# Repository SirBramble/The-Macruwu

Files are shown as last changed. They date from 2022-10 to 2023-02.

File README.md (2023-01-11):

# The Macruwu
The macro pad for all! (well, at least, if you can understand the Clusterfuck posted here)
The Firmware is based on the Arduino Pico Core by earlephilhower https://github.com/earlephilhower/arduino-pico. 

**This is only a brief overview** The full documentation and instructions can be found in the "Documentation"-folder.

## Components used

I went with the RP2040 based board from seeed studio. It has a fast chip, offers integrated USB support and is only about 6€. However, it has limited GPIO pins. So if you want to build your own, I would recommend using I/O Expanders or something similar. Another option would be to use a raspberry Pi with a RP2040. This Board beaks out most of the RP2040 Pins and has Options for Wi-Fi.

In order to try out different Key switches and keep the Macruwu modular, I decided to use hot swap sockets. They aren’t to expensive, if you order them for AliExpress (about 1\$/10psc). But beware, when soldering. If your board manufacturer decides to give you the shit coating on your Pads, prepare for heavy flux use.

For the I/O Expanders I used the PCA9555 from NXP. They conveniently don’t need a lot of setup and are automatically set to INPUT_PULLUP. The detailed Addressing scheme and co can be found in the Datasheet. But, as per usual nowadays, the I/O expanders are sold out. So, you might want to look for them somewhere else, or find a suitable replacement. But if you can find them, I can recommend the NXP Expanders. They need minimal to no Software Setup and I haven't had a dead one so far.

The level shifter (TXU0104PWR) is a cheap option I got from Mouser. It has 4 channels it can shift and is enough for the two 5V I²C Lines and the neopixel line.

The keyswitches were purchased for AliExpress and some smaller Keyboard parts suppliers. I like clicky switches, so I went for the Gateron greens. However, I cannot recommend them. They sound quite hollow and scratchy. Could maybe fixed with some lube *gigidy*, but it’s not really worth the trouble. 
If you want some really clicky Keyswitches, that will any the hell out of anybody in a 30km Radius, you could go for the Kailh Low profile Chock whites. My, extremely pissed of, fellow student can confirm. However, be aware that they can not be used with relegendable keycaps.
## How to compile

### With the Arduino IDE 2.0
First download the Code either from the repo or via the release tab. Put it in a folder and open the ```Macruwu_OS.ino``` file.

In order to compile the Code, you need to install the Arduino Pico core. There is a Tutorial on how to do this on earlephilhowers GitHub. You will also need the Adafruit SPIFlash Library. It can be downloaded via the Library Manager. The rest should be included in the Pico Core.
If you get Library conflicts, I'm afraid you're on you’re own. I somehow got it to compile and haven’t touched my setup since. No Idea why it suddenly worked, but the only thing I can recommend, is to back up your libraries and start fresh.

EDIT: If you get a Library conflict, you may want to look for other Bugs. Sometimes the Arduino IDE shows this message, just to inform you, that it has used a certain Library. However, your Code may not compile due to another error.

Also remember to change the USB Stack to the Adafruit TinyUsb Stack via Tools->USB Stack.
If you want to use the inbuilt Flash as a drive, you also have to allocate Memory under Tools->Flash Size. The first time you allocate Memory, you will have to format it. Just doing it in Windows should be fine.
P.s. The flash drive code is more or less copied from Adafruit. sorry, I was lazy...

### With PlatformIO
Well... I have no Idea, but let me know, if you find out.

## How to use (isch...)

The Macruwu OS is divided in to several Files for maximum ```'someFuckingShit' is not defined did you mean 'goFuckYourself'?```

### With macroLayout.txt

NOTE: The first time you start the Macruwu, you might have problem, with it crashing. This may be caused by the File not being present in the Flash directory. You may have to disable the ```readFile```-function in the ```Keyboard::init```-function in ```Keyboard.cpp``` and upload the File first. Then reenable the function and it should run.

The Layout can be set with several Commands. ```Layer x: ``` sets the Layer under which the Buttons will be accessible. ```Button x: {string}``` sets the Button and is followed by the string, that will be printed by the keyboard. Remember to leave a space between ```:``` and ```{string}```. This is due to the way that the file gets read. The Character straight after the ```:``` will be ignored.

So far, most characters will be interpreted correctly, however ```<``` and ```>``` have a special Meaning. They press the left and right arrow keys respectively. Verry useful for Macro pads that print code with a lot of Brackets. Other functions have not yet been implemented, but feel free to add them in the ```Keyboard.cpp``` under ```Keyboard::interpet```.

In order to read the file from the Flash in to the Data structure you want to run the ```readFile```-function at least once. I recommend running it once in ```setup()``` and then running it each time the file is changed. this can be done with:
```
if(Macruwu.fsChanged()){
    Macruwu.readFile();
  }
```

In order to run the commands that have been set in the Data structure you will have to run the ```interpret(layer, button)```-function.

### With Hardcoded Mapping
The Keymapping can be set in the ```Mapping.cpp```.

In order to write something over USB, you can use ```Keyboard1.write("something");``` But this only works for most normal characters like letters and sometimes other specialty symbols. You'll have to try it out. Things like Brackets or things that use function keys, will have to be set up manually. This can either be done, by sending the commands via the Tiny USB library directly, or by adding a new function to the Keyboard class. But look through the Keyboard class, as I may add more functions in the future.

**Word of Warning:** If you do not have a US Keyboard, be prepared for some HID Code treasure hunting. I haven’t found a way to change the layout, so you either have to find a Layout and redefine all the keys in the library, or just try and hope you find what you need. If you have a German Keyboard layout set, you can reference the code for some mappings.

## Bugs
Yes

## Further documentation
I recommend reading the documentation by earlephilhower https://github.com/earlephilhower/arduino-pico. It´s a far better than this clusterfuck, but feel free to look through the code.

And in case you didn't read the first 3 lines, you can find more documentation in the "Documentation"-folder.

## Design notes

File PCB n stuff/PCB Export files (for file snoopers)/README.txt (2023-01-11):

This stuff was created by the EasyEDA export tools. They are SHIT. And I mean realy SHIT! Most files are glitchy and the only things that work well, are the Gerber files.
Well, at least something. But if you want to snoop arround the exported stuff, feel free. If it helps, even better.

Edit: I tried getting the PCB converted to kicad, but it did not work as intended. Like I said, the EasyEDA exports are bricked.
There is a V2 in the works, created with kicad, but this will still take some time.
I exported the EasyEDA project files as json files, so you can at least check out the PCB within EasyEDA.

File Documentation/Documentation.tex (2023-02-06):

\documentclass[english, 12pt]{scrartcl}
\usepackage{caladea}
%\usepackage{gfsartemisia-euler}
\usepackage[
a4paper,
left=2.5cm,
right=2.5cm,
top= 2cm,
bottom = 2.5cm,
footskip = 1.5cm
]{geometry}
\usepackage{fancyhdr}
\usepackage[english]{babel}
\usepackage[T1]{fontenc}
\usepackage{graphicx,float}
\graphicspath{ {./images/} }
\usepackage{wrapfig}
\usepackage{caption}
\usepackage{pdfpages}
\usepackage{makecell}
\usepackage{subfiles}
\usepackage{enumitem,amssymb}
\usepackage{lastpage}
%\usepackage{amsmath}
\usepackage{esint}
\usepackage{blindtext}
\usepackage{hyperref}
\hypersetup{
	colorlinks=true,
	linkcolor=black,
	filecolor=magenta,      
	urlcolor=cyan,
	pdftitle={The Macruwu},
	pdfpagemode=FullScreen,
}
\urlstyle{same}
\usepackage[inkscapeformat=png]{svg}
\usepackage{tikz}
\usetikzlibrary{shapes.geometric, arrows}
\usepackage[
% school,
simplified
]{pgf-umlcd}
\usepackage{listings}
\usepackage{color}
\definecolor{listinggray}{gray}{0.92}

\pagestyle{fancy}

\title{\fontfamily{}\selectfont The Macruwu}
\author{Bramble}
\date{}
\begin{document}
	\maketitle
	
	\tableofcontents
	\newpage
	\section{Incentive}
	My handwriting is something any doctor would be proud of. My teachers, however, were not so enamoured with my writing prowess, often deducting grades for sheer illegibility. So when I went to uni, I started taking notes digitally. First, I tried my luck with OneNote and a digital pen, hoping somehow it would improve my notetaking-ability. But when that inevitably failed, I switched to Word. For those who have never tried, writing equations in Word is a pain in the back side. It takes ages and especially when equations get more complex, it's a nightmare to try and get the $e^{x}$ to go, where you want it to go.\\
	So I switched once more.I went for Markdown with inline $L^AT_EX$. Markdown is a markup language that can easily run in a browser and like $L^AT_EX$ it's "what you mean is what you get". It has simple syntax, making it easy to learn, but also supports inline $L^AT_EX$, which is very useful when writing equations. The hoster we (my friends and I) use also supports multiple people working on the same document in real time, which makes taking notes a lot faster and also allows one person to be sketching graphs and the like, while the rest of us try our best to keep up with the professor.\\
	But even with Markdown and multiple people writing at the same time, it just took too long and we sometimes missed some important notes.\\

	\begin{wrapfigure}{r}{0.25\textwidth}
		\vspace{-0.8cm}
		\centering
		
		\caption{Macropad v0.1}
	\end{wrapfigure}
	\noindent One afternoon I therefore cobbled together my first macro pad out of some Cherry switches and a Teensy I had lying around. It was extremely botched and had no fancy features to speak of, but it worked. That got me hooked. Even with just eight extra keys, I was able to write a lot faster. So I went back to the drawing board and started designing what was to become the Macruwu.
	\section{Requirements}
	For this macropad to be of any use to me, it needed to fulfil certain requirements.
	\begin{itemize}
		\item It needed to be compatible with any system. This meant it needed to work, no matter which computer I plugged it in to. This also meant that I couldn't rely on any software that had to be running in the background.
		\item It should be able to type out any key combination that would also be possible on a normal keyboard. This would make it universally useable for practically any software, because almost all software can be controlled easily with shortcuts from a keyboard.
		\item It must not hinder my workflow. This means that using the Macruwu should always be faster than typing out the command or character strings by hand.
		\item It needed to be fast. I wanted as little delay as possible, so that long strings of characters could be printed quickly. For complex equation presets a maximum delay of about 300-400ms would be optimal.
		\item Mappings should be changeable on the fly. If, for example, a certain equation were to show up consistently in the lecture, it should be possible to assign that equation to a key quickly and easily.
		\item It should be expandable. If 32 keys aren't enough or if I want to add some kind of other interface device or expansion module, it should be possible to interface it with the Macruwu.
		\item It MUST have RGB. I could try and think up some reason for why it's necessary to have RGB, but I just want RGB uwu.
		\item It should be affordable. The goal for this project was to stay under 70€ per unit.
		\item It should be repairable. For me this meant, creating options for most kinds of mechanical keyswitches. If a switch breaks or if I want to later replace them with different ones, it should be easy to just rip´em out and stick in some ones.
	\end{itemize}
	\newpage
	\section{Choices of component}
	\subsection{Microcontroller}
	For the microcontroller, I chose the seeed studio RP2040. It´s a small board, even smaller, than a Teensy, but it allows you to configure it as an HID with very little effort. It's also very fast and has a humongous 2MB of flash, which can also be configured as a mountable flash drive. It doesn't have a lot of pins but it does have a number of broken out connections, namely two I$^2$C lines, an SPI bus and even a UART port if you need it. And USB-C is just the cherry on top (no pun intended).\newline
	If you want to learn more, you can check out the \href{https://wiki.seeedstudio.com/XIAO-RP2040/}{Seeed Wiki}. This is good to get you started with the microcontroller, but if you want more information on the programming side, you should check out Earle Philhowers Arduino Pico \href{https://github.com/earlephilhower/arduino-pico}{GitHub} and \href{https://arduino-pico.readthedocs.io/en/latest/}{documentation}.
	
	\subsection{I/O expanders}
	In order to read the keyswitch inputs some kind of I/O expander was needed. I just went for the cheapest I could find on Mouser that was still in stock. It turned out to be the \href{https://www.mouser.de/datasheet/2/302/PCA9555-1127545.pdf}{PCA9555D}, a double 8-bit I/O expander that can be read via I$^2$C. It offers internal pull-up resistors, which was a nice bonus, meaning I didn't have to add them to the design. However, bear in mind that you might have to add some to your design if you want to use a different I/O expander.
	
	\subsection{Level shifter}
	The RP2040 is a 3.3V microcontroller. In order to use 5V logic devices, a level shifter is needed. This is optional, however. If you don't plan on using the NeoPixels or 5V I$^2$C devices, you can just leave it out. At first I used the \href{https://www.ti.com/lit/gpn/txu0104}{TXU0104PWR} which is a unidirectional chip. This works great for the NeoPixels, but won't work for the 5V I$^2$C due to this being a bidirectional protocol. However Texas Instruments offers a pin-equivalent bi-directional chip, the \href{https://www.ti.com/lit/gpn/lsf0204-q1}{LSF0204-Q1}. I haven't tested it so far, but the datasheet indicates that this should be a drop-in replacement.
	
	\subsection{RGB goodness}
	In order to satisfy my endless need for funny blinky lights, I picked up some \href{https://de.aliexpress.com/item/1005003636607308.html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}{SK6803 MINI-Es} from AliExpress. They come in 3mA and 12mA versions. In order to not overtax the USB power, I'd recommend getting the 3mA version. They should be more than bright enough. If you want to burn out your retinas, you can also go for the 12mA version, but bear in mind that you may run into Voltage drops when running them at the full 12mA.\newline
	One of the most useful features of the SK6803 MINI-Es is their ability to be mounted through a cutout in the PCB, making them sit flush with the surface. This allows the use of most switches. They also have a identical addressing scheme to standard NeoPixels and can be controlled by the Adafruit Neopixel library.
	
	\subsection{Hot-swap sockets}
	In order to change keyswitches without having to solder, some sort of hot-swap socket is needed. I chose \href{https://keycapsss.com/keyboard-parts/parts/49/kailh-hotswap-pcb-sockets-10-pcs?c=11}{Kailh hot-swap sockets}. They're easy to solder and work a lot better than the push-in ones you might find on commercial hot-swap boards. They also come in versions for MX- and Choc-style keyswitches.
	
	\subsection{Keyswitches}
	This is pure preference. I love clicky keys, so I went for the clickiest (reasonably priced) keys I could find. The \href{https://de.aliexpress.com/item/32980039972.html}{Gateron greens} are a very affordable option for MX style keys and are quite clicky. If you want maximum click for a bit more cash, you can check out the \href{https://keycapsss.com/switchestester/switches/65/kailh-low-profile-choc-switches?c=9}{Kailh whites}. They provide maximum click and are guaranteed to annoy the living heck out of most sane people. Needless to say I absolutely love them.\newline
	If you prefer not to make everyone within a 30Km radius go completely insane, you can also choose a tactile or linear switch. Both the Gateron and Kailh keys offer those options. If you want to fall in to a very deep rabbit hole, you can also look up keyswitches on YouTube. Trust me, it's worth it.
	
	\subsection{Keycaps}
	Now here there are several options. You can 3D-print your keycaps on a resin printer or print flat ones on an FDM printer and label them afterwards. You can get quite creative with custom keycaps. If you don't want to print your own, \href{https://de.aliexpress.com/item/1005003047698548.html}{relegendable keycaps} are always an option and the one I went for. A printable template for the keycap inlays is in the main GitHub repository.
	
	\subsection{I$^2$C Jacks}
	To connect the Macruwu to other input devices I used a \href{https://keycapsss.com/keyboard-parts/parts/54/2x-trrs-jacks-3.5mm?c=11}{3.5mm 4-pin headphone jack}. This breaks out 3.3V, GND, SCL, SDA and offers the option to use a wide variety of fancy cables.
	\newpage
	\section{Hardware}
	
	\subsection{Full schematics}
	\begin{figure}[H]
		\centering
		
		\caption{Sheet 1 of the Macruwu}
	\end{figure}
	\begin{figure}[H]
		\centering
		
		\caption{Sheet 2 of the Macruwu}
	\end{figure}
	\begin{figure}[H]
		\centering
		
		\caption{PCB frame 1 of the Macruwu}
	\end{figure}
	\begin{figure}[H]
		\centering
		
		\caption{PCB frame 2 of the Macruwu}
	\end{figure}
	\begin{figure}[H]
		\centering
		
		\caption{PCB frame 3 of the Macruwu}
	\end{figure}
	\begin{figure}[H]
		\centering
		
		\caption{PCB frame 4 of the Macruwu}
	\end{figure}
	\begin{figure}[H]
		\centering
		
		\caption{PCB frame 5 of the Macruwu}
	\end{figure}
	
	\subsection{Soldering tips}
	SMD soldering is a pain, but in this case necessary. If you've never soldered SMD before or if it's been a while, here are some tips:
	\begin{itemize}
		\item Start with the smallest components. I'd recommend starting with the SMD capacitors. They're really fiddly, but are good for practice, especially if you haven't soldered SMD before. If you mess up, they're also easy to remove letting you try again. And if you manage to solder all the capacitors, the rest shouldn't be a problem.\newline
		\textbf{NOTE:} When soldering the capacitors, leave out the ones near the ICs and do them later. They might get in the way when soldering the ICs.
		\item When soldering the ICs, start by tinning a single pad. Once you've tinned one pad, heat it up and push the IC in to place. Then you can solder the rest of the connections.
		\item Use flux. It's not strictly necessary but it does help a lot, especially when using lead-free solder. If you find yourself getting a lot of bridges or cold solder joints, give flux a try. It really does help. I personally use the \href{https://www.amazon.de/FELDER-L%C3%B6tfett-L%C3%B6tmittel-Solder-L%C3%B6tpaste/dp/B01822CUO6}{flux paste you get in those small tins} but any flux is better than none.
		\item Have some solder wick lying around. If you find yourself unable to separate a bridge on an IC, you'll want solder wick. Ideally apply some flux to the wick, place it on the solder joints you want to disconnect and press your soldering iron on top. This should pull any unnecessary solder in to the wick.\newline
		\textbf{NOTE:} Don't pull the solder wick around the connection or PCB. This will scrape away the solder mask and may expose or cut traces. I found that out the hard way...
		\item When soldering in the hot-swap sockets and RGB LEDs, make sure they're properly soldered to the board. Ground pads especially tend to result in cold solder joints. Use flux and check your connections with a multimeter. For the hot-swap sockets you can increase the temperature to about 370-400°C, but try not to keep the iron on there for too long if you do. With the LEDs I'd recommend not going above 360°C because if you do, they might break. I haven´t had this happen before, but bear this in mind.
		\item Clean your board after soldering. You can use isopropanol or similar non conducting cleaning liquids. This is to prevent corrosion and general stickiness from the flux.
	\end{itemize}
	
	\section{Macruwu Firmware}
	This firmware is based on Earle Philhowers \href{https://github.com/earlephilhower/arduino-pico}{Arudino Pico} and includes some Adafruit libraries. Therefore, make sure to install them before trying to flash this code.
	\subsection{Structure}
	\textbf{NOTE:} I'm not studying computer science so this diagram may not be up to standard. However, I hope it gives you a brief overview of how the code is structured. This will be updated with code updates (hopefully).\newline
	\begin{minipage}{\linewidth}
		\centering
		\resizebox{0.5\textheight}{!}{\input{Classes/Keyboard}}
	\end{minipage}
	\newline
	\newline
	The basic idea of this code is to divide everything up in to separate modules that interface with one aother. This takes a bit more effort to try and get the separate modules working together, but once it's set up, it's a lot easier to tweak.
	\subsubsection{Layer class}
	OK, so now lets go over the structure and start at the bottom. The \textit{Layer} class has a vector of strings. This stores all the plaintext commands associated with a certain button. So a \textit{Layer}-object has several buttons.
	\subsubsection{Keymap class}
	The \textit{Keymap} class has a vector of \textit{Layer}-objects. A \textit{Keymap}-object thus has several layers consisting of several buttons. You can imagine this as an array or a table, that allows you to look up which command is associated with a certain button on a certain layer.
	\subsubsection{Filesystem' functions}
	The \textit{Keymap} class can also access the file system using the \textit{import()} method. This method pulls the command strings from the \textit{macroLayout.txt}-file stored on the internal file system and saves them in the aforementioned \textit{Layer-Button}-structure.
	\subsubsection{Keyboard class}
	This construct is then controlled by the \textit{Keyboard}-class. This builds an interface for the \textit{main} to access but also introduces some functions of its own. The \textit{Keyboard}-class manages all the HID(human interface device)-commands and also houses the interpreter to convert the command strings to sendable HID key-codes. This is done internally for the most part, but exposes all the relevant interface methods to the main. For example, the \textit{interpret(layer, button)}-method interprets and runs the command stored in the command string at the given layer and button as an HID command.\newline
	\textbf{NOTE:} All HID commands are set to work with a German keyboard layout. Most of them still work with a US or similar layout, but you might have to change some special character keycodes like '\verb=^=' or '\verb=\='.\newline
	Edit: I found a overview of a keyboard with the corresponding key-codes depicted on every key. This should be universal to all Keyboards. May be useful...
	\begin{figure}[H]
		\centering
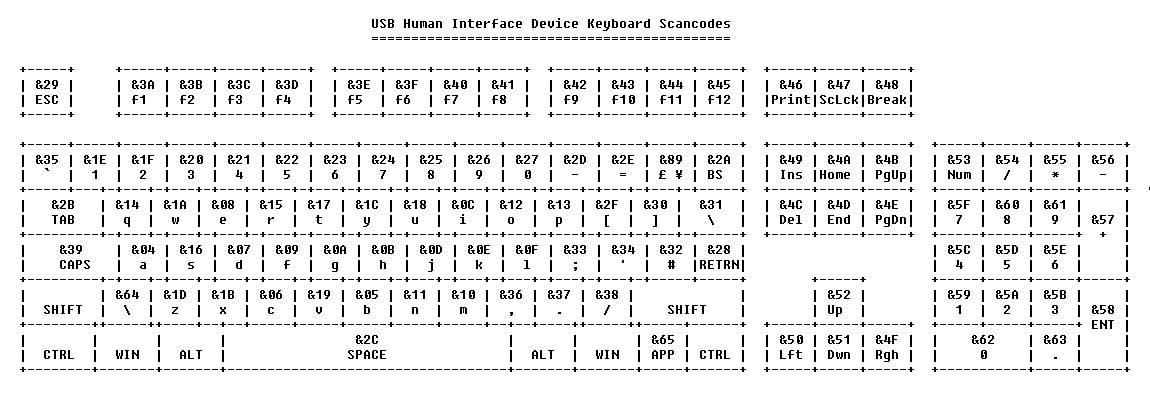
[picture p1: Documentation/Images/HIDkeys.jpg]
		
		\caption{Mapped HID Keys}
	\end{figure}
	
	\noindent There are also other methods included in the class. The \textit{readFile()}-method in combination with the \textit{fsChanged()}-method can auto-update the \textit{Layer-Button}-structure from the \textit{macroLayout.txt}-file whenever the file is edited.
	\subsubsection{NoePixel functions}
	So far not a lot has been done here. These are just a few function prototypes saved in a separate file. \textit{neopixelSetup()} simply initialises the Adafruit library and \textit{testNeopixel()} just runs a slow rainbow-effect.
	\subsubsection{Expander class}
	The \textit{Expander}-class is responsible for reading and debouncing the I/O expanders. The state of any pin on the I/O expander can be accessed via the \textit{getState} method.
	\subsubsection{Mapping module}
	This isn't shown in the diagram and is mainly for debugging and testing. The \textit{Mapping} module is a header and source file combination that creates its own \textit{Keyboard}-object and runs hardcoded sets of instructions when a button is pressed. The function of a certain button can be called from the main via the \textit{action(button)}-function.
	\subsection{AniMacro}
	The AniMacro scripting language (kinda) is used to tell the macropad what to type from the \textit{macroLayout.txt}. This is fully customisable and you can add your own commands in the \textit{Keyboard::interpret()} method if you are so inclined.\\
	The basic structure, however, is set by the \textit{readFile()}-method. With \textit{Layer x:} you set the current layer to x. Follow that with \textit{Button y: something} and you set button \textit{y} on layer \textit{x} to \textit{something}. Every \textit{Layer x:} or \textit{Button y: something} must be followed by a linebreak.\newline
	\textbf{For example:}\newline
	\noindent\fbox{%
		\parbox{\textwidth}{%
			\begin{tabbing}
				Layer 1:\= \\
				\> Button 1: something \\
				\> Button 2: something else \\
				Layer 2:\\
				\> Button 1: something on Layer 2
			\end{tabbing}
		}%
	}\newline
	\subsubsection{Implemented commands}
	\begin{tabular}{|l|m{6.5cm}|m{6.5cm}}
		\hline
		\textbf{Command} & \textbf{Description} & \textbf{Comment}\\
		\hline
		\hline
		\verb=Some text= & No operator prints plain text& \\
		\hline
		\verb=\plain{}= & Prints contents as plain text. Can print characters reserved for AniMacro commands. & Double Brackets \verb={}= will be printed. If the have contents (e.g. \verb={a}=), the plain command chain is broken and returned to the 'no Operator' state.\\
		\hline 
		\verb=<= & Moves screen cursor one step to the left (presses left arrow key) & \\
		\verb=>= & Moves screen cursor one step to the right (presses right arrow key) & \\
		\verb=\n= & Triggers the 'ENTER'-key & \\
		\verb=\t= & Triggers the 'TAB'-key & \\
		\hline
	\end{tabular}\\\\
	Most special characters can also be typed without a special command:\\
	\verb=\ ^ { } [ ] ( ) $ | _ . ,=
	
	\subsection{I$^2$C Expansion Port}
	\noindent
	The I$^2$C expansion port is used to connect peripherals to the Macruwu via a TRRS-jack. It can also be used to connect the Macruwu as a peripheral to another Macruwu. The Pins are as follows:
	\begin{center}
		\begin{tabular}{|c|c|c|c|}
			\hline
			Sleve&Ring 1& Ring 2& Tip\\
			\hline
			GND & SCL 3V3 & SDA 3V3 & 5V\\
			\hline
		\end{tabular}
	\end{center}

	\section{Debugging tips}
	\begin{figure}[H]
		\centering
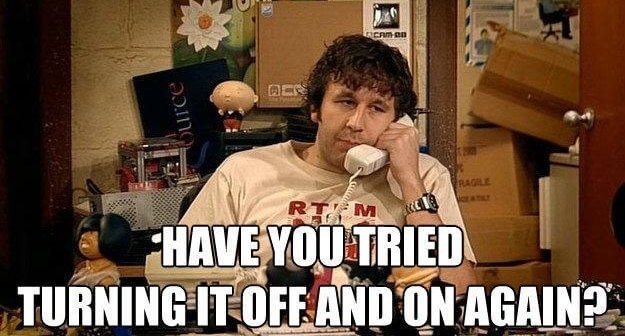
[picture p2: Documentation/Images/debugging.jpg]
		
		\caption{Debugging tips from the IT crowd}
	\end{figure}
	Sometimes the Macruwu gets stuck and cant get out (of an infinite loop or something). Unplugging it and plugging it back in again can help with that and works in 90\% of all cases.\\
	If this does not help, try the tips below.
	\subsection{Compiling firmware}
	\begin{itemize}
		\item Check whether you have the correct version of the Arduino Pico framework installed. I used the newest at the time, which was version 2.6.4.
		\item Also check, that you have the correct libraries installed.
		\subitem Adafruit NeoPixel by Adafruit (1.10.6)
		\subitem Adafruit SPIFlash by Adafruit (4.0.0)
		\subitem SdFat - Adafruit Fork by Bill Greiman (2.2.1)
		\item If you are using Platform I/O or similar, you may have to include files other than the main separately in the compiler config
	\end{itemize}
	\subsection{Microcontroller crashing}
	\begin{itemize}
		\item Try running the \textit{flash\_test()} function in the setup. This will create the \textit{macroLayout.txt} which if missing might cause the microcontroller to crash.
		\item If the microcontroller doesn't get recognised by the computer, try holding down the \textit{BOOT}-button on the microcontroller and while pressing it, plug the microcontroller back in to the computer. It will them show up as a new device, and COM port and you should be able to upload to it.
	\end{itemize}
	\subsection{Filesystem corrupted}
	This can happen, if the \textit{File read} protocol crashed, due to a illegal character in the \textit{macroLayout.txt} file on the flash. If this happens, please open a issue with the character, that caused the crash.\\
	There is a way to 'restore' it though.
	\begin{enumerate}
		\item Unplug the Macruwu and uncomment the \textit{flash\_clear()} command. This will clear the flash partition.
		\item Hold the \textit{BOOT} button (the on on the right) on the RP2040 and plug it in while pressing the button. This will manually set the microcontroller in to programming mode.
		\item Select the newly appeared COM port and press upload. You may have to restart the Arduino IDE several times throughout this process, if it is stuck in a infinite upload loop. Don´t worry, this will not break anything.
		\item Once uploaded, a new drive should show up. If you are under Windows you will be prompted to format the disc.
		\item Once formatted, you can upload a backup of the \textit{macroLayout.txt} or create a new one. DO NOT UNPLUG THE MACRUWU!
		\item Go to the Arduino IDE and comment or delete the \textit{flash\_clear()} command.
		\item Select the correct COM port and press upload. If the Arduino IDE is stuck in a infinite upload loop, restart the IDE. 
		\item It should be working normally again.
	\end{enumerate}
	\subsection{NeoPixels not working}
	\begin{itemize}
		\item Check the solder connections. If the NeoPixels are not properly soldered on to the pads they will not work. Even one improperly soldered NeoPixel may cause the others to act funny. I recommend checking each connection with a multimeter, by connecting one probe to $GND$ or $5V$ respectively and going through the respective pins on the NeoPixels with the other.
		\item If $5V$ and $GND$ are connected correctly, but you are still having trouble, check the connection between the Neopixels. $D_{out}$ of one and $D_{in}$ of the next in the chain should always be connected.
	\end{itemize}
	\subsection{I/O expanders not working}
	\begin{itemize}
		\item Check the solder connections
		\item Make sure your I/O Expanders have internal pull-up resistors. If they do not, they will not work with the Macruwu board. If you have your own board, you can also add them on the PCB, however, I did not do that with mine.
		\item Make sure you have set the correct address. The Base address can be found in the datasheet of the I/O expander and the variable address pars can be found in the Macruwu schematic. If you are using the same I/O listed in the materials section, the preset address should be correct.
		\item If you are using different I/O expanders from the ones listed in the materials section, make sure the I$^2$C addressing scheme is correct. Other I/O expanders may need to be configured differently from the ones I used. If it turns out that you do need a setup sequence for your I/O expanders, you can create a \textit{init()} method in the \textit{Expander} class and call it in the \textit{setup()}.
	\end{itemize}
	\subsection{some buttons are not being recognised}
	\begin{itemize}
		\item Check the solder connections on the hot-swap sockets. They tend to form cold solder joints, that you may not always see. Especially the GND pad tends to do this. Check the connection with a multimeter by holding one probe to a known GND and going through the other connections with the other probe. The same can be done for the other side of the socket. Hold one probe on the socket and the other on the corresponding I/O expander pin.
		\item Make sure the key switch is installed correctly. The pins do tend to bend when pressing them in. you can check from the underside of the board, if the pin is seated in the hot-swap socket. If not, pull it out, straighten out the pin with a pair of pliers and press it back in.
	\end{itemize}
	If none of the above helped, fell free to contact me.\\
	Discord: Bramble\#2342
\end{document}

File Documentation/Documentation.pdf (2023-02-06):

## The Macruwu

## Bramble

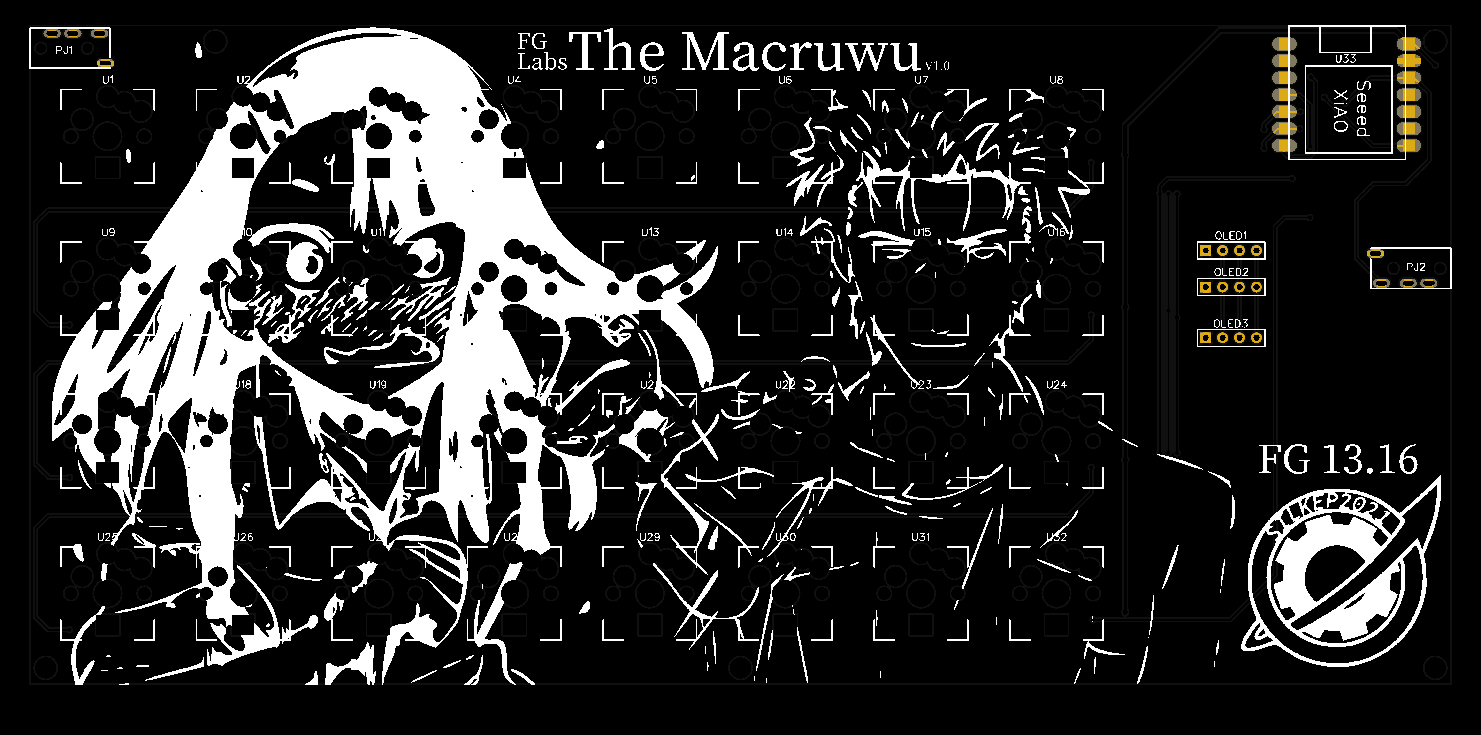
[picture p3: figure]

## Contents

1 Incentive | 3
2 Requirements | 3
3 Choices of component | 5
4 Hardware | 7
5 Macruwu Firmware | 11

Contents | Contents
6 Debugging tips | 14

2 REQUIREMENTS

## 1 Incentive

My handwriting is something any doctor would be proud of. My teachers, however, were not so enamoured with my writing prowess, often deducting grades for sheer illegibility. So when I went to uni, I started taking notes digitally. First, I tried my luck with OneNote and a digital pen, hoping somehow it would improve my notetaking-ability. But when that inevitably failed, I switched to Word. For those who have never tried, writing equations in Word is a pain in the back side. It takes ages and especially when equations get more complex, it’s a nightmare to try and get the e

x
to go, where you want it to go. So I switched once more.I went for Markdown with inline L

ATEX. Markdown is a markup language that can easily run in a browser and like L

ATEX it’s "what you mean is what you get". It has simple syntax, making it easy to learn, but also supports inline L

ATEX, which
is very useful when writing equations. The hoster we (my friends and I) use also supports multiple people working on the same document in real time, which makes taking notes a lot faster and also allows one person to be sketching graphs and the like, while the rest of us try our best to keep up with the professor.
But even with Markdown and multiple people writing at the same time, it just took too long and we sometimes missed some important notes.

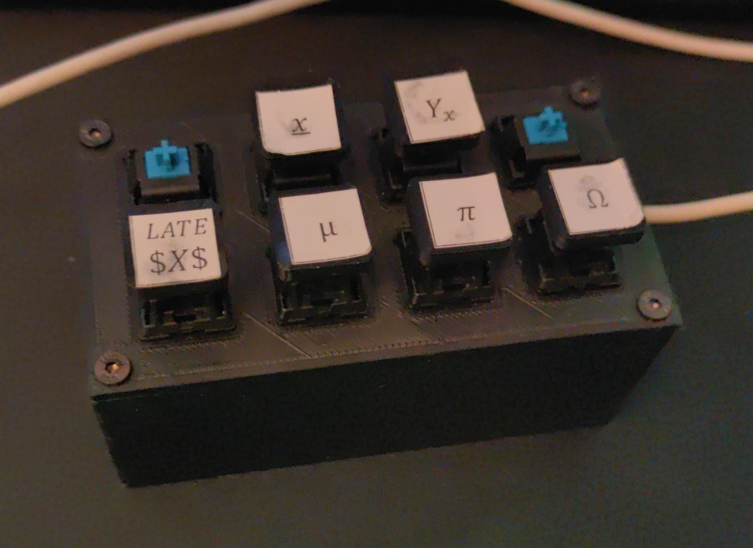
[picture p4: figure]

Figure 1: Macropad
v0.1

One afternoon I therefore cobbled together my first macro pad out of some Cherry switches and a Teensy I had lying around. It was extremely botched and had no fancy features to speak of, but it worked. That got me hooked. Even with just eight extra keys, I was able to write a lot faster. So I went back to the drawing board and started designing what was to become the Macruwu.

## 2 Requirements

For this macropad to be of any use to me, it needed to fulfil certain
requirements.
- It needed to be compatible with any system. This meant it needed to work, no matter which computer I plugged it in to. This also meant that I couldn’t rely on any software that had to be running in the background.
- It should be able to type out any key combination that would also be possible on a normal keyboard. This would make it universally useable for practically any software, because almost all software can be controlled easily with shortcuts from a keyboard.
- It must not hinder my workflow. This means that using the Macruwu should always be faster than typing out the command or character strings by hand.
- It needed to be fast. I wanted as little delay as possible, so that long strings of characters could be printed quickly. For complex equation presets a maximum delay of about 300-400ms would be optimal.
- Mappings should be changeable on the fly. If, for example, a certain equation were to show up consistently in the lecture, it should be possible to assign that equation to a key quickly and easily.

2 REQUIREMENTS

- It should be expandable. If 32 keys aren’t enough or if I want to add some kind of other interface device or expansion module, it should be possible to interface it with the Macruwu.
- It MUST have RGB. I could try and think up some reason for why it’s necessary to have RGB, but I just want RGB uwu.
- It should be affordable. The goal for this project was to stay under 70€ per unit.
- It should be repairable. For me this meant, creating options for most kinds of mechanical keyswitches. If a switch breaks or if I want to later replace them with different ones, it should be easy to just rip´em out and stick in some ones.

3 CHOICES OF COMPONENT

## 3 Choices of component

### 3.1 Microcontroller

For the microcontroller, I chose the seeed studio RP2040. It´s a small board, even smaller, than a Teensy, but it allows you to configure it as an HID with very little effort. It’s also very fast and has a humongous 2MB of flash, which can also be configured as a mountable flash drive. It doesn’t have a lot of pins but it does have a number of broken out connections, namely two I²C lines, an SPI bus and even a UART port if you need it. And USB-C is just the cherry on top (no pun intended).
If you want to learn more, you can check out the Seeed Wiki. (https://wiki.seeedstudio.com/XIAO-RP2040/) This is good to get you started with the microcontroller, but if you want more information on the programming side, you should check out Earle Philhowers Arduino Pico GitHub (https://github.com/earlephilhower/arduino-pico) and documentation. (https://arduino-pico.readthedocs.io/en/latest/)

### 3.2 I/O expanders

In order to read the keyswitch inputs some kind of I/O expander was needed. I just went for the cheapest I could find on Mouser that was still in stock. It turned out to be the PCA9555D, (https://www.mouser.de/datasheet/2/302/PCA9555-1127545.pdf) a double 8-bit I/O expander that can be read via I²C. It offers internal pull-up resistors, which was a nice bonus, meaning I didn’t have to add them to the design. However, bear in mind that you might have to add some to your design if you want to use a different I/O expander.

### 3.3 Level shifter

The RP2040 is a 3.3V microcontroller. In order to use 5V logic devices, a level shifter is needed. This is optional, however. If you don’t plan on using the NeoPixels or 5V I²C devices, you can just leave it out. At first I used the TXU0104PWR (https://www.ti.com/lit/gpn/txu0104) which is a unidirectional chip. This works great for the NeoPixels, but won’t work for the 5V I²C due to this being a bidirectional protocol. However Texas Instruments offers a pin-equivalent bi-directional chip, the LSF0204-Q1. (https://www.ti.com/lit/gpn/lsf0204-q1) I haven’t tested it so far, but the datasheet indicates that this should be a drop-in replacement.

### 3.4 RGB goodness

In order to satisfy my endless need for funny blinky lights, I picked up some SK6803 MINI-Es (https://de.aliexpress.com/item/1005003636607308.html) from AliExpress. They come in 3mA and 12mA versions. In order to not overtax the USB power, I’d recommend getting the 3mA version. They should be more than bright enough. If you want to burn out your retinas, you can also go for the 12mA version, but bear in mind that you may run into Voltage drops when running them at the full 12mA.
One of the most useful features of the SK6803 MINI-Es is their ability to be mounted through a cutout in the PCB, making them sit flush with the surface. This allows the use of most switches. They also have a identical addressing scheme to standard NeoPixels and can be controlled by the Adafruit Neopixel library.

### 3.5 Hot-swap sockets

In order to change keyswitches without having to solder, some sort of hot-swap socket is needed. I chose Kailh hot-swap sockets. (https://keycapsss.com/keyboard-parts/parts/49/kailh-hotswap-pcb-sockets-10-pcs?c=11) They’re easy to solder and work a lot better

3.6 Keyswitches | 3 CHOICES OF COMPONENT

than the push-in ones you might find on commercial hot-swap boards. They also come in versions for MX- and Choc-style keyswitches.

### 3.6 Keyswitches

This is pure preference. I love clicky keys, so I went for the clickiest (reasonably priced) keys I could find. The Gateron greens (https://de.aliexpress.com/item/32980039972.html) are a very affordable option for MX style keys and are quite clicky. If you want maximum click for a bit more cash, you can check out the Kailh whites. (https://keycapsss.com/switchestester/switches/65/kailh-low-profile-choc-switches?c=9) They provide maximum click and are guaranteed to annoy the living heck out of most sane people. Needless to say I absolutely love them.
If you prefer not to make everyone within a 30Km radius go completely insane, you can also choose a tactile or linear switch. Both the Gateron and Kailh keys offer those options. If you want to fall in to a very deep rabbit hole, you can also look up keyswitches on YouTube. Trust me, it’s worth it.

### 3.7 Keycaps

Now here there are several options. You can 3D-print your keycaps on a resin printer or print flat ones on an FDM printer and label them afterwards. You can get quite creative with custom keycaps. If you don’t want to print your own, relegendable keycaps (https://de.aliexpress.com/item/1005003047698548.html) are always an option and the one I went for. A printable template for the keycap inlays is in the main GitHub repository.

### 3.8 I²C Jacks

To connect the Macruwu to other input devices I used a 3.5mm 4-pin headphone jack. (https://keycapsss.com/keyboard-parts/parts/54/2x-trrs-jacks-3.5mm?c=11) This breaks out 3.3V, GND, SCL, SDA and offers the option to use a wide variety of fancy cables.

## 4 Hardware

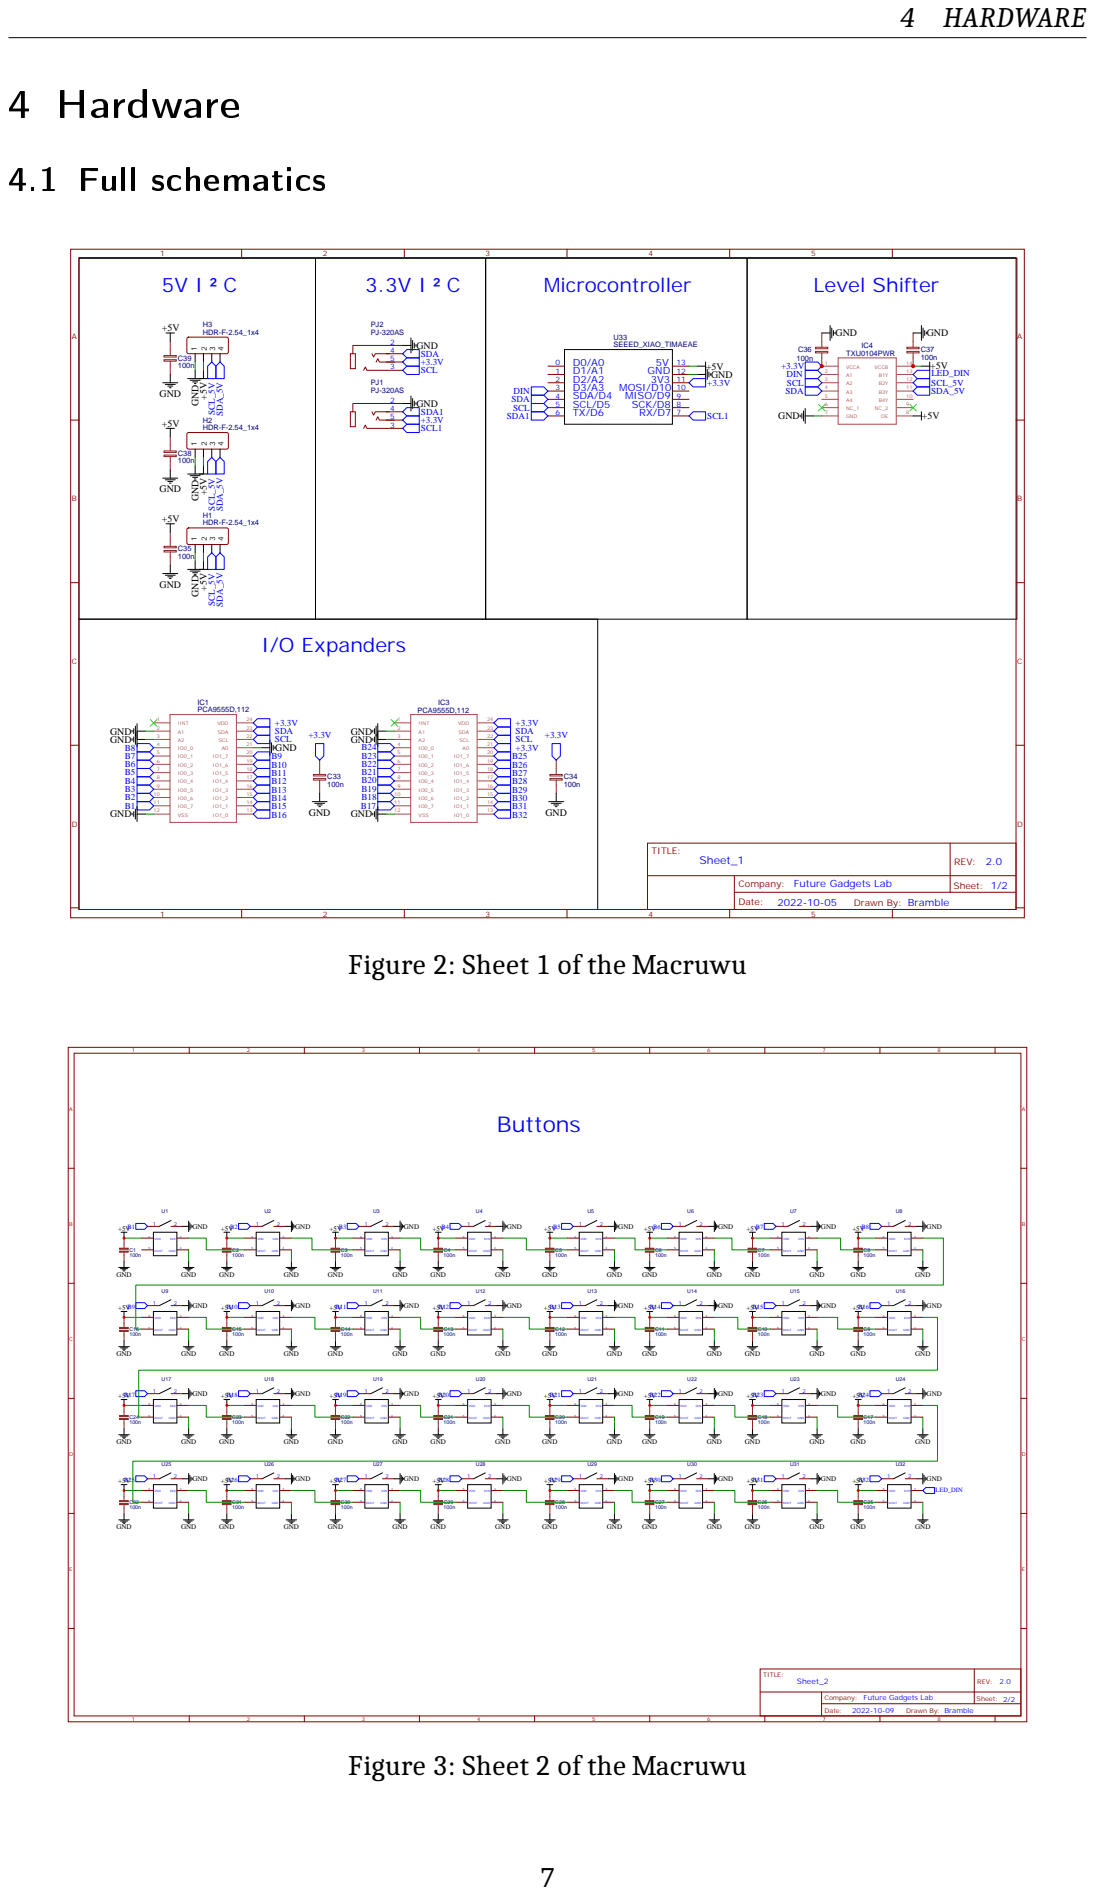
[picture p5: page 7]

Company: Future Gadgets Lab

Figure 2: Sheet 1 of the Macruwu

Figure 3: Sheet 2 of the Macruwu

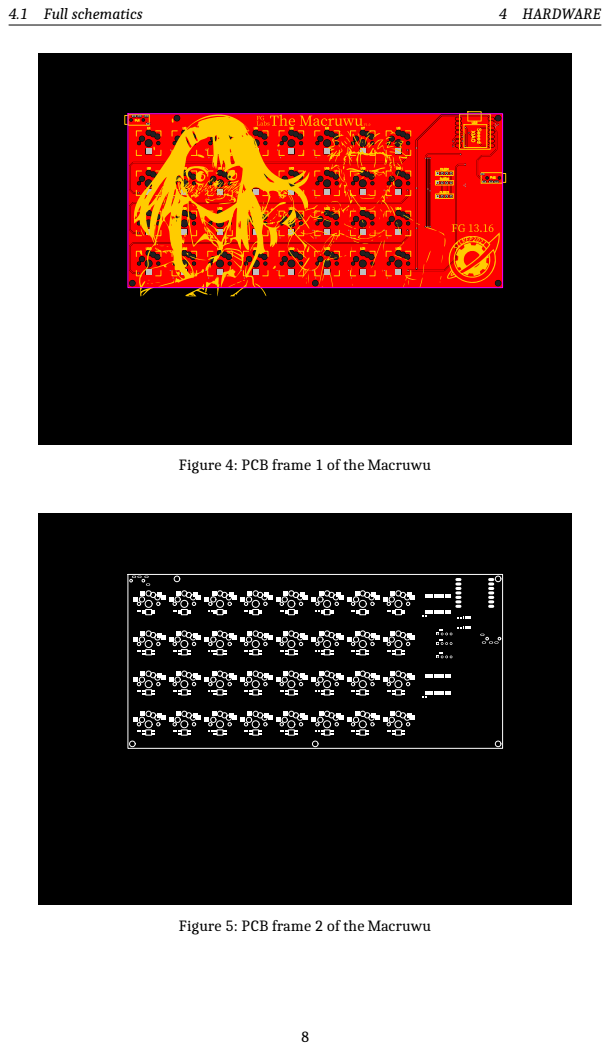
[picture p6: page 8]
4.1 Full schematics; 4 HARDWARE

Figure 4: PCB frame 1 of the Macruwu

Figure 5: PCB frame 2 of the Macruwu

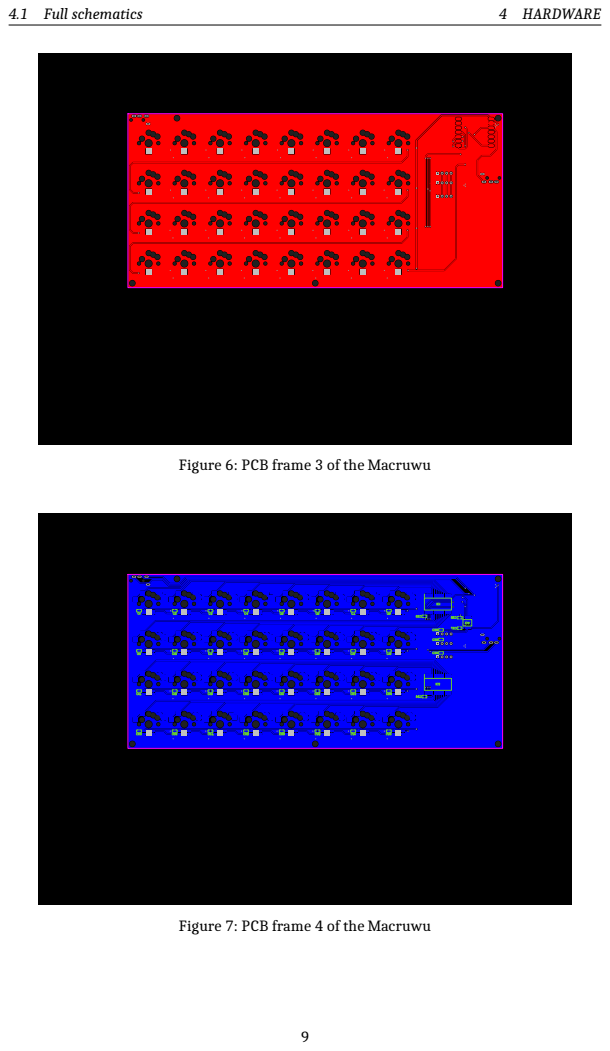
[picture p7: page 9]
4.1 Full schematics; 4 HARDWARE

Figure 6: PCB frame 3 of the Macruwu

Figure 7: PCB frame 4 of the Macruwu

4.2 Soldering tips | 4 HARDWARE

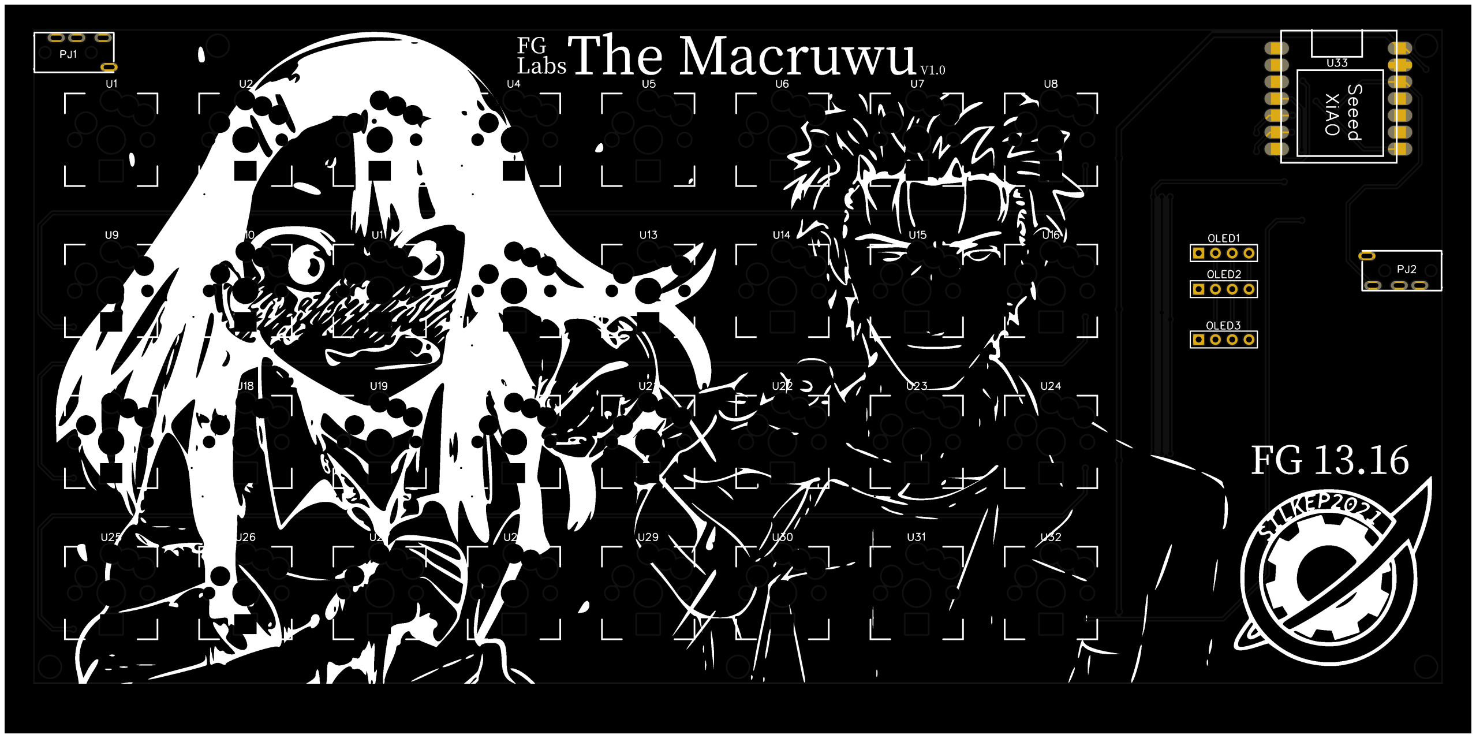
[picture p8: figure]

Figure 8: PCB frame 5 of the Macruwu

### 4.2 Soldering tips

SMD soldering is a pain, but in this case necessary. If you’ve never soldered SMD before or if it’s been a while, here are some tips:

- Start with the smallest components. I’d recommend starting with the SMD capacitors. They’re really fiddly, but are good for practice, especially if you haven’t soldered SMD before. If you mess up, they’re also easy to remove letting you try again. And if you manage to solder all the capacitors, the rest shouldn’t be a problem.
NOTE: When soldering the capacitors, leave out the ones near the ICs and do them later. They might get in the way when soldering the ICs.
- When soldering the ICs, start by tinning a single pad. Once you’ve tinned one pad, heat it up and push the IC in to place. Then you can solder the rest of the connections.
- Use flux. It’s not strictly necessary but it does help a lot, especially when using leadfree solder. If you find yourself getting a lot of bridges or cold solder joints, give flux a try. It really does help. I personally use the flux paste you get in those small tins (https://www.amazon.de/FELDER-L%C3%B6tfett-L%C3%B6tmittel-Solder-L%C3%B6tpaste/dp/B01822CUO6) but any flux is better than none.
- Have some solder wick lying around. If you find yourself unable to separate a bridge on an IC, you’ll want solder wick. Ideally apply some flux to the wick, place it on the solder joints you want to disconnect and press your soldering iron on top. This should pull any unnecessary solder in to the wick.
NOTE:Don’t pull the solder wick around the connection or PCB. This will scrape away the solder mask and may expose or cut traces. I found that out the hard way...
- When soldering in the hot-swap sockets and RGB LEDs, make sure they’re properly soldered to the board. Ground pads especially tend to result in cold solder joints. Use flux and check your connections with a multimeter. For the hot-swap sockets you can increase the temperature to about 370-400°C, but try not to keep the iron on there for too long if you do. With the LEDs I’d recommend not going above 360°C because if you do, they might break. I haven´t had this happen before, but bear this in mind.
- Clean your board after soldering. You can use isopropanol or similar non conducting cleaning liquids. This is to prevent corrosion and general stickiness from the flux.

5 MACRUWU FIRMWARE

## 5 Macruwu Firmware

This firmware is based on Earle Philhowers Arudino Pico (https://github.com/earlephilhower/arduino-pico) and includes some Adafruit libraries. Therefore, make sure to install them before trying to flash this code.

### 5.1 Structure

NOTE: I’m not studying computer science so this diagram may not be up to standard. However, I hope it gives you a brief overview of how the code is structured. This will be updated with code updates (hopefully).

main

Keyboard

- ammountLayers : int
- ammountKeys : int
- modifier : uint8_t
- report_id : uint8_t = 0
- sendString : String
- filename : String
- buffer[6] : uint8_t = 0
- bufferSetFlag : bool
- keymap_ptr : Keymap *
- send(uint8_t mod = 0) : void
- isLetterSmall(char c) : bool
- clearBuffer(void) : void
- setBuffer(uint8_t index, uint8_t value) : void
- bufferClear(void) : bool
+ Keyboard(String filename = "macroLayout.txt", int ammountLayers = 5, int ammountkeys = 32)
+ init(void) : void
+ get_string_from_file(int layer, int button) : String
+ set_string_in_file(int layer, int button, String string_to_write) : void + readFile(void) : void
+ interpret(int layer, int button) : void
+ write(String text) : void
+ backslash(void) : void
+ goLeft(uint8_t ammount) : void
+ goRight(uint8_t ammount) : void
+ brackets(bool goToMiddle = 0) : void
+ bracketsSquare(bool goToMiddle) : void
+ writeKeycode(uint8_t Keycode, uint8_t Modifier = 0) : void + fsChanged(void) : void

nopixel

+ neopixelSetup() : void
+ testNeopixel() : void

Expander

- address : uint8_t
- state[16] : uint8_t
- state_prev[16] : uint8_t
- state_db[16] : uint8_t
- input_reg[2] : uint8_t
- db_time_prev : uint64_t = millis()
- splice() : void
- debounce() : bool
+ Expander(uint8_t address_get) + getState(uint8_t pin) : bool
+ update() : void

filesystem

+ flash_setup() : void
+ flash_loop() : void
+ flash_test() : void
+ check_fs_changed() : bool
+ set_fs_changed(bool fs_changend_in) : void

Keymap

- Layers : vector <Layer>
- currentLayer : int
- ammountLayers : int
- ammountKeys : int
- filename : String
- getNum(String tmp) : int
- getString(String tmp) : String
+ Keymap(String filname, int ammountLayers, int ammountKeys) + init(void) : void
+ import(void) : void
+ get(int indexLayer, int indexButton) : String
+ set(int indexLayer, int indexButton, String funktion_string) : void

Layer

- Button : vector <String>

+ Layer(int ammountKeys)
set(int indexButton, String funktionString) : void
get(int indexButton) : String
The basic idea of this code is to divide everything up in to separate modules that interface with one aother. This takes a bit more effort to try and get the separate modules working together, but once it’s set up, it’s a lot easier to tweak.

5.1.1 Layer class

OK, so now lets go over the structure and start at the bottom. The Layer class has a vector of strings. This stores all the plaintext commands associated with a certain button. So a Layer-object has several buttons.

5.1.2 Keymap class

The Keymap class has a vector of Layer-objects. A Keymap-object thus has several layers consisting of several buttons. You can imagine this as an array or a table, that allows you to look up which command is associated with a certain button on a certain layer.

5.1 Structure | 5 MACRUWU FIRMWARE

5.1.3 Filesystem' functions

The Keymap class can also access the file system using the import() method. This method pulls the command strings from the macroLayout.txt-file stored on the internal file system and saves them in the aforementioned Layer-Button-structure.

5.1.4 Keyboard class

This construct is then controlled by the Keyboard-class. This builds an interface for the main to access but also introduces some functions of its own. The Keyboard-class manages all the HID(human interface device)-commands and also houses the interpreter to convert the command strings to sendable HID key-codes. This is done internally for the most part, but exposes all the relevant interface methods to the main. For example, the interpret(layer, button)-method interprets and runs the command stored in the command string at the given layer and button as an HID command.
NOTE: All HID commands are set to work with a German keyboard layout. Most of them still work with a US or similar layout, but you might have to change some special character keycodes like ’^’ or ’\’.
Edit: I found a overview of a keyboard with the corresponding key-codes depicted on every key. This should be universal to all Keyboards. May be useful...

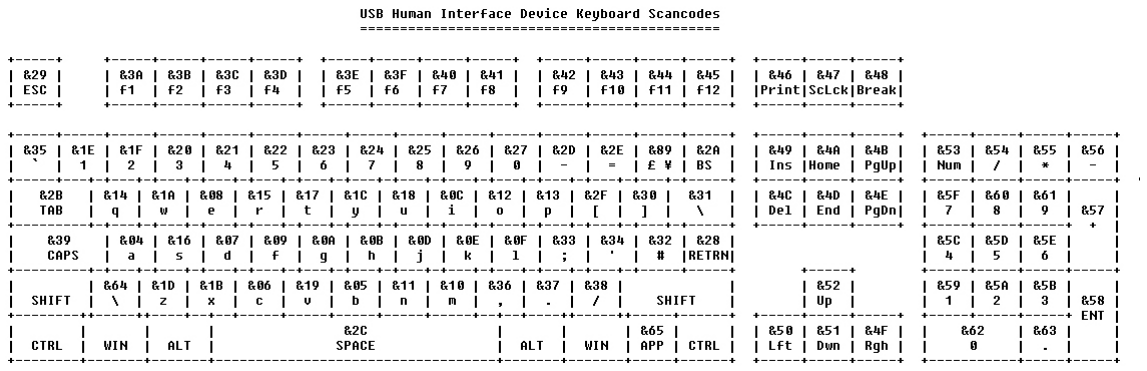
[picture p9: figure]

Figure 9: Mapped HID Keys

There are also other methods included in the class. The readFile()-method in combination with the fsChanged()-method can auto-update the Layer-Button-structure from the macro-Layout.txt-file whenever the file is edited.

5.1.5 NoePixel functions

So far not a lot has been done here. These are just a few function prototypes saved in a separate file. neopixelSetup() simply initialises the Adafruit library and testNeopixel() just runs a slow rainbow-effect.

5.1.6 Expander class

The Expander-class is responsible for reading and debouncing the I/O expanders. The state of any pin on the I/O expander can be accessed via the getState method.

5.2 AniMacro | 5 MACRUWU FIRMWARE

5.1.7 Mapping module

This isn’t shown in the diagram and is mainly for debugging and testing. The Mapping module is a header and source file combination that creates its own Keyboard-object and runs hardcoded sets of instructions when a button is pressed. The function of a certain button can be called from the main via the action(button)-function.

### 5.2 AniMacro

The AniMacro scripting language (kinda) is used to tell the macropad what to type from the macroLayout.txt. This is fully customisable and you can add your own commands in the Keyboard::interpret() method if you are so inclined.
The basic structure, however, is set by the readFile()-method. With Layer x: you set the current layer to x. Follow that with Button y: something and you set button y on layer x to something. Every Layer x: or Button y: something must be followed by a linebreak.
For example:

Layer 1:
Button 1: something
Button 2: something else
Layer 2:
Button 1: something on Layer 2

5.2.1 Implemented commands

Command | Description | Comment
Some text | No operator prints plain text
\plain{} | Prints contents as plain text. Can
| print characters reserved for Ani-
| Macro commands. | Double Brackets {} will be printed.
| | If the have contents (e.g. {a}), the
| | plain command chain is broken and
| | returned to the ’no Operator’ state.
< | Moves screen cursor one step to the
| left (presses left arrow key)
> | Moves screen cursor one step to the
| right (presses right arrow key)
\n | Triggers the ’ENTER’-key
\t | Triggers the ’TAB’-key

Most special characters can also be typed without a special command:
\ ^ { } [ ] ( ) $ | _ . ,

### 5.3 I²C Expansion Port

The I²C expansion port is used to connect peripherals to the Macruwu via a TRRS-jack. It can also be used to connect the Macruwu as a peripheral to another Macruwu. The Pins are as follows:

Sleve | Ring 1 | Ring 2 | Tip
GND | SCL 3V3 | SDA 3V3 | 5V

6 DEBUGGING TIPS

## 6 Debugging tips

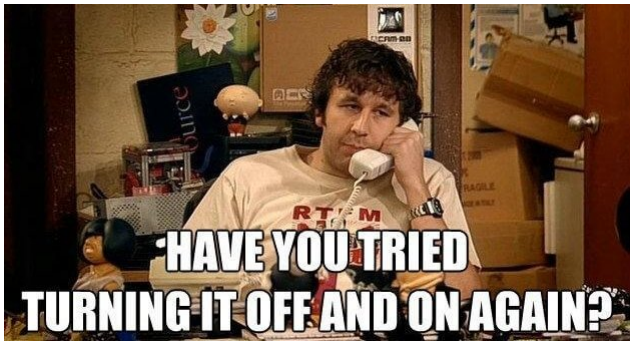
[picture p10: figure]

Figure 10: Debugging tips from the IT crowd

Sometimes the Macruwu gets stuck and cant get out (of an infinite loop or something). Unplugging it and plugging it back in again can help with that and works in 90% of all cases.
If this does not help, try the tips below.

### 6.1 Compiling rmware

- Check whether you have the correct version of the Arduino Pico framework installed. I used the newest at the time, which was version 2.6.4.
- Also check, that you have the correct libraries installed.

Adafruit NeoPixel by Adafruit (1.10.6)

Adafruit SPIFlash by Adafruit (4.0.0)

SdFat - Adafruit Fork by Bill Greiman (2.2.1)

- If you are using Platform I/O or similar, you may have to include files other than the main separately in the compiler config

### 6.2 Microcontroller crashing

- Try running the flash_test()function in the setup. This will create themacroLayout.txt which if missing might cause the microcontroller to crash.
- If the microcontroller doesn’t get recognised by the computer, try holding down the BOOT-button on the microcontroller and while pressing it, plug the microcontroller back in to the computer. It will them show up as a new device, and COM port and you should be able to upload to it.

6.3 Filesystem corrupted | 6 DEBUGGING TIPS

### 6.3 Filesystem corrupted

This can happen, if the File read protocol crashed, due to a illegal character in the macro-Layout.txt file on the flash. If this happens, please open a issue with the character, that caused the crash.
There is a way to ’restore’ it though.
1. Unplug the Macruwu and uncomment the flash_clear() command. This will clear the flash partition.
2. Hold the BOOT button (the on on the right) on the RP2040 and plug it in while pressing the button. This will manually set the microcontroller in to programming mode.
3. Select the newly appeared COM port and press upload. You may have to restart the Arduino IDE several times throughout this process, if it is stuck in a infinite upload loop. Don´t worry, this will not break anything.
4. Once uploaded, a new drive should show up. If you are under Windows you will be prompted to format the disc.
5. Once formatted, you can upload a backup of the macroLayout.txt or create a new one. DO NOT UNPLUG THE MACRUWU!
6. Go to the Arduino IDE and comment or delete the flash_clear() command.
7. Select the correct COM port and press upload. If the Arduino IDE is stuck in a infinite upload loop, restart the IDE.
8. It should be working normally again.

### 6.4 NeoPixels not working

- Check the solder connections. If the NeoPixels are not properly soldered on to the pads they will not work. Even one improperly soldered NeoPixel may cause the others to act funny. I recommend checking each connection with a multimeter, by connecting one probe to GND or 5V respectively and going through the respective pins on the NeoPixels with the other.
- If 5V and GND are connected correctly, but you are still having trouble, check the connection between the Neopixels. Dout of one and Din of the next in the chain should always be connected.

### 6.5 I/O expanders not working

- Check the solder connections
- Make sure your I/O Expanders have internal pull-up resistors. If they do not, they will not work with the Macruwu board. If you have your own board, you can also add them on the PCB, however, I did not do that with mine.
- Make sure you have set the correct address. The Base address can be found in the datasheet of the I/O expander and the variable address pars can be found in the Macruwu schematic. If you are using the same I/O listed in the materials section, the preset address should be correct.

6.6 some buttons are not being recognised | 6 DEBUGGING TIPS
- If you are using different I/O expanders from the ones listed in the materials section, make sure the I²C addressing scheme is correct. Other I/O expanders may need to be configured differently from the ones I used. If it turns out that you do need a setup sequence for your I/O expanders, you can create a init() method in the Expander class and call it in the setup().

### 6.6 some buttons are not being recognised

- Check the solder connections on the hot-swap sockets. They tend to form cold solder joints, that you may not always see. Especially the GND pad tends to do this. Check the connection with a multimeter by holding one probe to a known GND and going through the other connections with the other probe. The same can be done for the other side of the socket. Hold one probe on the socket and the other on the corresponding I/O expander pin.
- Make sure the key switch is installed correctly. The pins do tend to bend when pressing them in. you can check from the underside of the board, if the pin is seated in the hot-swap socket. If not, pull it out, straighten out the pin with a pair of pliers and press it back in.

If none of the above helped, fell free to contact me.
Discord: Bramble#2342

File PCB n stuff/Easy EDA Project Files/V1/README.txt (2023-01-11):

            
How to use：

At editor, open the document via: Top menu - File - Open - EasyEDA... , and select the json file, then open it at the editor, you can save it into a project.

如何使用：

打开编辑器，通过：顶部菜单 - 文件 - 打开 - 立创EDA... ，选择 json 文件打开在编辑器，你可以保存文档进工程里面。

This file was created by the EasyEDA file export tool thing. And a merry uwu to you too.

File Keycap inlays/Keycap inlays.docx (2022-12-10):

x/y | e | y^x | x | y_x | √x | ∞ | $$
( xyz ) | [ x, ya, b ] | x | × | ∣x∣
{xy | ab}
∑_x^y a | ∫_x^y a | limx→ya

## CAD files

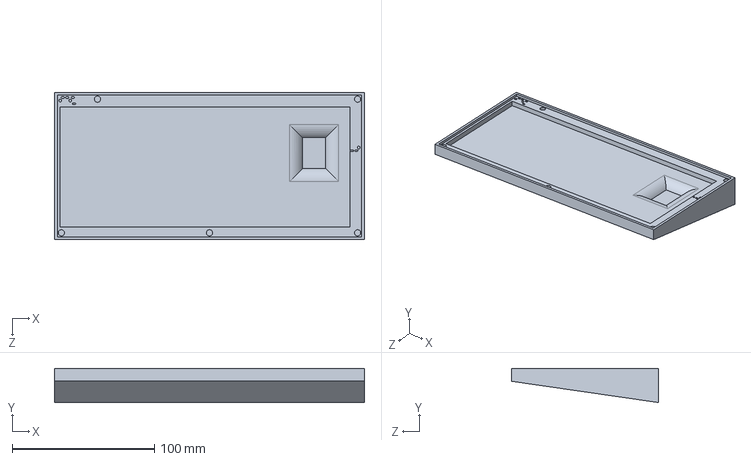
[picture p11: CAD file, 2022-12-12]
3D Models/Body/Body no Display.STEP
218.0 x 24.0 x 103.7 mm

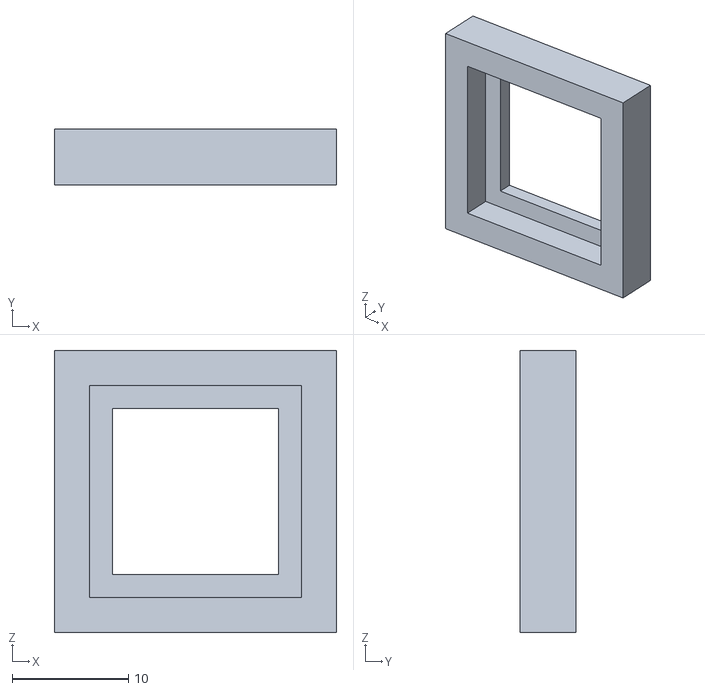
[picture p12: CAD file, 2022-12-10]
3D Models/Keyplate Holder testfits/Keyplate Holder test 14.3mm.STL
24.3 x 4.80 x 24.3

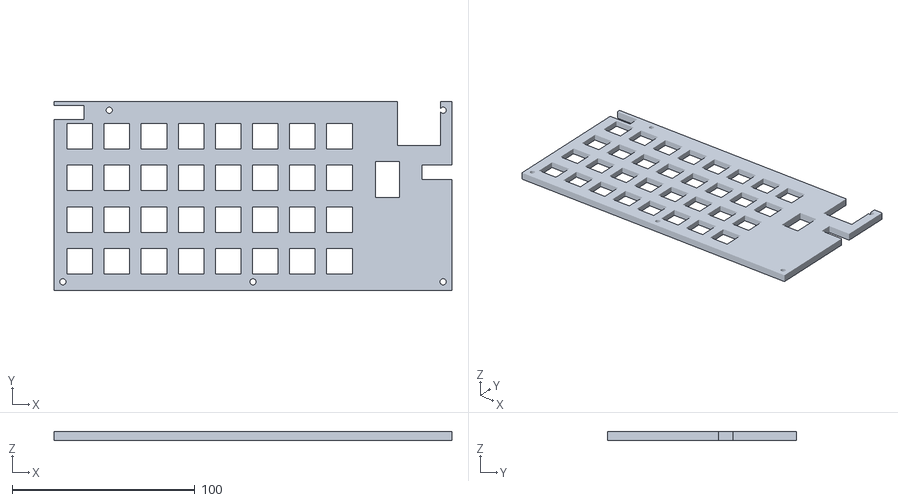
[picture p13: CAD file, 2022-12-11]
3D Models/Keyplate/Keyplate 14.0mm.STL
218.0 x 103.7 x 4.80

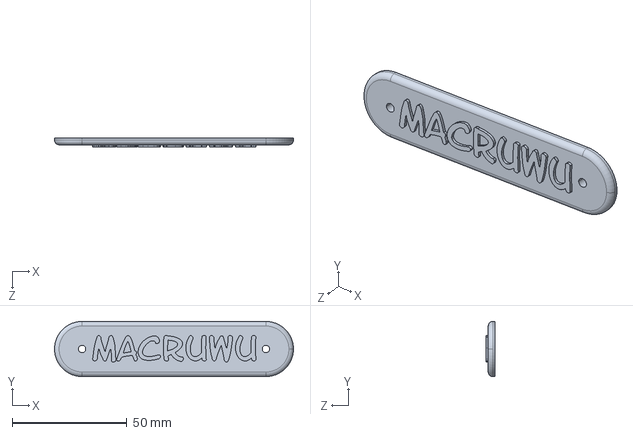
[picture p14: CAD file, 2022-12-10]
3D Models/Nameplate/Nameplate.STEP
104.0 x 24.0 x 4.00 mm

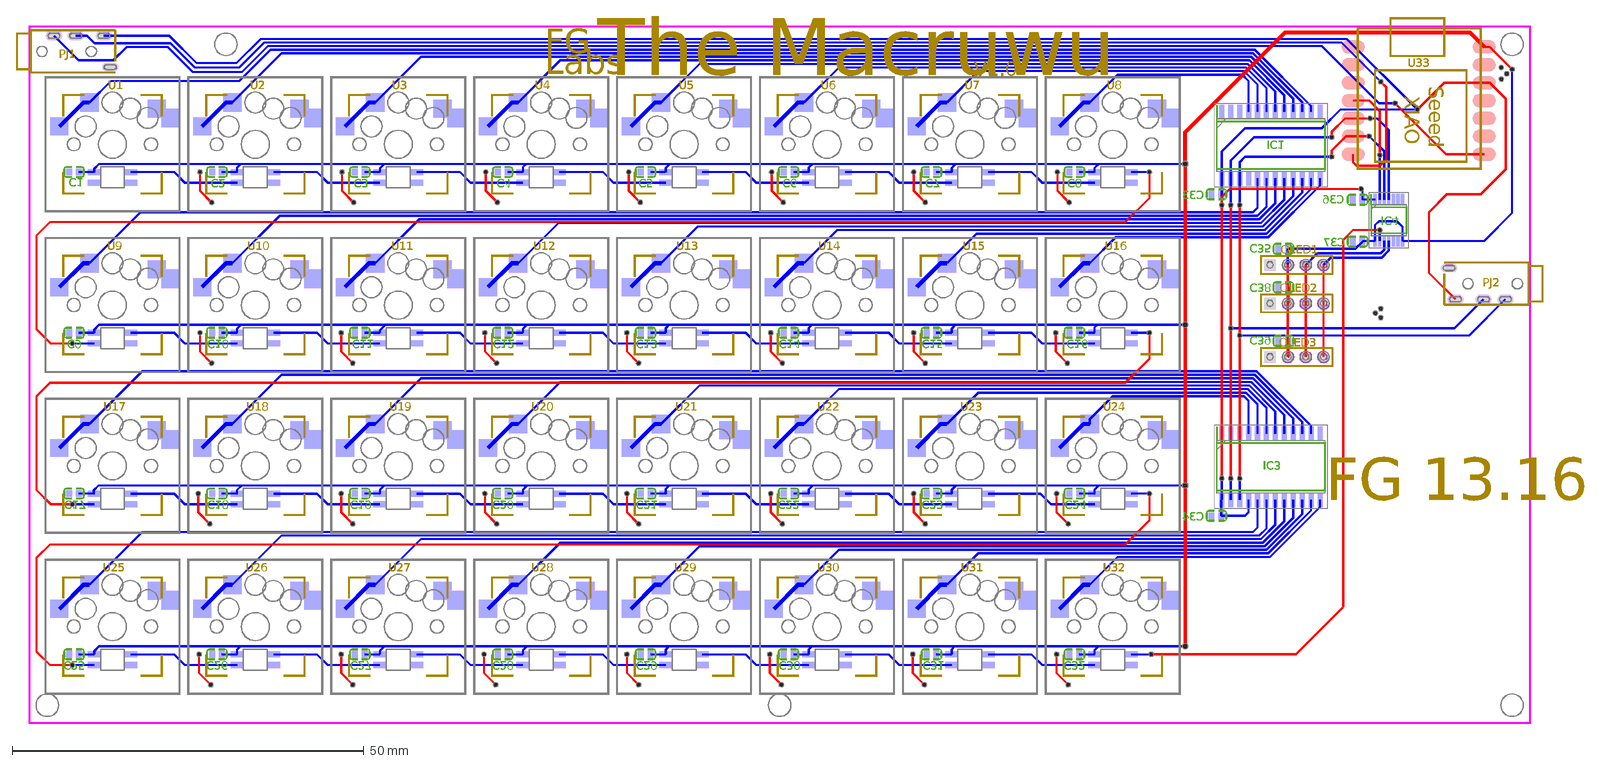
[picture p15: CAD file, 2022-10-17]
PCB n stuff/PCB Export files (for file snoopers)/PCB_Macro Pad_2022-10-13.dxf
The Macruwu
FG
Labs
FG 13.16
V1.0
C38
C39
OLED2
OLED3
PJ1
PJ2
OLED1
U1
U2
U3
U4
U5
U6
U7
U8
U9
U10
U11
U12
U13
U14
U15
U16
U17
U18
U19
U20
U21
U22
U23
U24
U25
U26
U27
U28
U29
U30
U31
U32
U33
Seeed
XIAO
C1
C2
C3
C4
C5
C6
C7
C8
C33
C34
C35
C36
C37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

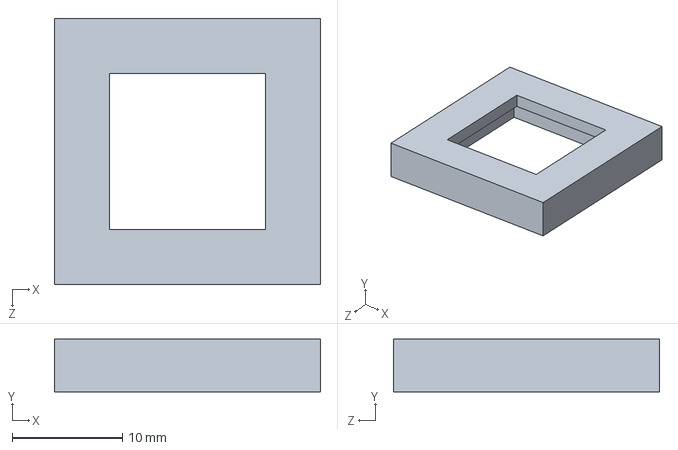
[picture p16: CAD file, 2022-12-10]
3D Models/Keyplate Holder testfits/Keyplate Holder test.STEP
24.1 x 4.80 x 24.1 mm

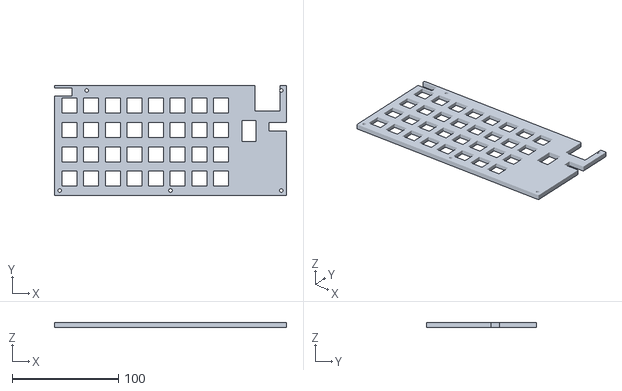
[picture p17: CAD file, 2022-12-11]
3D Models/Keyplate/Keyplate 14.1mm.STL
218.0 x 103.7 x 4.80

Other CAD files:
3D Models/Keyplate Holder testfits/Keyplate Holder test 14.0mm.STL
3D Models/Keyplate/Keyplate 14.2mm.STL
3D Models/Keyplate Holder testfits/Keyplate Holder test 14.1mm.STL
3D Models/Keyplate/Keyplate 14.3mm.STL
3D Models/Keyplate Holder testfits/Keyplate Holder test 14.2mm.STL
3D Models/Keyplate/Keyplate.STEP
3D Models/Body/Body no Display.STL
3D Models/Nameplate/Nameplate.STL

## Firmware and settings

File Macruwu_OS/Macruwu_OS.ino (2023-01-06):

//DISCLAIMER:
//My spelling is shit, so please ignore the spelling mistakes in the comments.
//Thx uwu

#include <Wire.h>

#define DEBUG false

#include "Expander.h"
#include "Mapping.h"
#include "Keyboard.h"
#include "Neopixel.h"


#define ADDone 0b0100000        
#define ADDtwo 0b0100001

Expander Expander1(ADDone);
Expander Expander2(ADDtwo);


//default Constructor. Initialises the Keyboard with: layout file: "macroLayout.txt", Layers: 5, Buttons: 32
Keyboard Macruwu;

// To change default parameters, call the constructor with arguments: 
// Keyboard Keyboard_Name("FILENAME", AMMOUNT_LAYERS, AMMOUNT_KEYS);
// For Example:
// Keyboard Macruwu("macroLayout.txt", 5, 32);           


void setup() {
  Serial.begin(115200);       //Open Serial Port at 115200 baud
  Wire.begin();               //start I²C for I/O expanders
  flash_setup();              //Setup flash storage as mounted drive
  //flash_test();             //try running if flsh storage won´t work. will try to create File and run some Tests.
                              //concider running it on call in loop(), due to a bug, where Serial prints are not sent from setup()
  //flash_clear();            //If your filesystem or mapping file is corrupted, run this to clear the storage
  //keyboardSetup();          //use this, if you with to use the Hardcoded Mapping
  Macruwu.init();             //Setup code for file mapped Keyboard
  neopixelSetup();            //Setup code for Neopixels

  Serial.println("done innit?");
}

void loop() {
  //debug_serial();           //Meant for testing the switches via the Serial Monitor
  //flash_loop();             //Try running this if you are having problems with the flash storage
  
  if(Macruwu.fsChanged()){
    Macruwu.readFile();
  }

  run();
  testNeopixel();
  delay(1);
}

void debug_serial(){              //For testing the Inputs
  for(int i = 0; i < 16; i++){
    if(Expander1.getStatePulse(i)){
      Serial.print("Button ");
      Serial.println(i);
      }  
  }
  for(int i = 0; i < 16; i++){
    if(Expander2.getStatePulse(i)){
      Serial.print("Button ");
      Serial.println(i+16);
      }  
  }
}

void run(){
  for(int i = 0; i < 16; i++){
    if(Expander1.getStatePulse(i)){
      //action(i);              //enable if you wish to run hardcoded mapping
      long before = millis();
      Macruwu.interpret(1, i);
      Serial.print("Time taken: "); Serial.println(millis()-before);
    }
  }
  for(int i = 0; i < 16; i++){
    if(Expander2.getStatePulse(i)){
      //action(i+16);           //enable if you wish to run hardcoded mapping
      long before = millis();
      Macruwu.interpret(1, i+16);
      Serial.print("Time taken: "); Serial.println(millis()-before);
    }
  }
  
  
}

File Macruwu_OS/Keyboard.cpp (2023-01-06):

#include "Keyboard.h"

uint8_t const conv_table[128][2] =  { HID_ASCII_TO_KEYCODE };
uint8_t const desc_hid_report[] ={ TUD_HID_REPORT_DESC_KEYBOARD() };
Adafruit_USBD_HID usb_hid(desc_hid_report, sizeof(desc_hid_report), HID_ITF_PROTOCOL_KEYBOARD, 2, false);

Keyboard::Keyboard(String filename, int ammountLayers, int ammountKeys){
    this->filename = filename;
    this->ammountLayers = ammountLayers;
    this->ammountKeys = ammountKeys;
}

void Keyboard::readFile(){
    keymap_ptr->import();
}

String Keyboard::get_string_from_file(int layer, int button){
    return keymap_ptr->get(layer, button);
}

void Keyboard::set_string_in_file(int layer, int button, String string_to_write){
    keymap_ptr->set(layer, button, string_to_write);
}
void Keyboard::interpret(int layer, int button){
  String stringToInterpret = keymap_ptr->get(layer,button);
  char charToInterpret;
  bool inBuffer = 0;
  String bufferString;
  for(uint32_t i = 0; i<stringToInterpret.length(); i++){
    charToInterpret = stringToInterpret.charAt(i);
    #ifdef SERIAL_DEBUG
    Serial.print(this->plainFlag);
    #endif
/////////////////////////////////////////////////////////////////Commands/////////////////////////////////////////////////////////////////
    if(this->plainFlag == 0){
      if(charToInterpret == 92){                  //checks for '\'
        if(stringToInterpret.charAt(i+1) == 'n'){
          this->writeKeycode(HID_KEY_ENTER);
          i++;
          continue;
        }
        if(stringToInterpret.charAt(i+1) == 't'){
          this->writeKeycode(HID_KEY_TAB);
          i++;
          continue;
        }
        if(stringToInterpret.indexOf("plain{", i+1) == i+1){
          i += 6;
          this->plainFlag = 1;
          #ifdef SERIAL_DEBUG
          Serial.print("plain flag set");
          #endif
          continue;
        }
      }
    }
/////////////////////////////////////////////////////////////plain text/////////////////////////////////////////////////////////////////
    if(((charToInterpret >= 65)&&(charToInterpret <= 90))||((charToInterpret >= 97)&&(charToInterpret <= 122))||(charToInterpret == ' ')||(charToInterpret == '.')||((charToInterpret >= 48)&&(charToInterpret <= 57))){    //checks for printable Letters with the write funktion
      inBuffer = 1;               //fill up the bufferString until the nect character is not part if the printable characters of the write() funktion
      bufferString += charToInterpret;
      continue;
    }
    else if(inBuffer){              //if the read character is no longer part of the printable write() characters, send the bufferString
      this->write(bufferString);
      bufferString.remove(0, (bufferString.length()));
      inBuffer = 0;
    }
    if(charToInterpret == '<'){                 //checks for '<'and triggers the left arrow key
        if(this->plainFlag == 1){               //If the plain flag is set with the '\plain' command, '<' is printed as a character
          this->writeKeycode(0x64);
          continue;
        }
        this->goLeft(1);                        //DO NOT ADD 'continue;'. THIS WILL BREAK EVERYTHING! (dont know why...)
      }
    if(charToInterpret == '>'){                 //checks for '>' and triggers the right arrow key
      if(this->plainFlag == 1){                 //If the plain flag is set with the '\plain' command, '>' is printed as a character
        this->writeKeycode(0x64, KEYBOARD_MODIFIER_LEFTSHIFT);
        continue;
      }
      this->goRight(1);                         //DO NOT ADD 'continue;'. THIS WILL BREAK EVERYTHING! (dont know why...)
    }
    if(charToInterpret == '|'){                 //checks for '|'
      this->writeKeycode(0x64, KEYBOARD_MODIFIER_RIGHTALT);
      continue;
    }
    if(charToInterpret == '$'){                 //checks for '$'
      this->write("$");
      continue;
    }
    if(charToInterpret == '_'){                 //checks for '_'
      this->writeKeycode(56, KEYBOARD_MODIFIER_LEFTSHIFT);
      continue;
    }
    if(charToInterpret == '{'){                 //checks for '{'
      if(stringToInterpret.charAt(i+1) == 125){ //checks next character for '}' and if found, sends both brackets at once (to save time)
        this->brackets();
        i++;
      }
      else{
        this->writeKeycode(HID_KEY_7, KEYBOARD_MODIFIER_RIGHTALT);  //if second bracket not found, send single bracket
      }
      continue;
    }
    if(charToInterpret == '}'){                 //checks for '}'
      if(this->plainFlag == 1){
        this->plainFlag = 0;
        i++;
        continue;
      }
      this->writeKeycode(HID_KEY_0, KEYBOARD_MODIFIER_RIGHTALT);
      continue;
    }
    if(charToInterpret == '['){                 //checks for '['
        if(stringToInterpret.charAt(i+1) == ']'){   //checks next character for ']' and if found, sends both square brackets at once (to save time)
            this->bracketsSquare();
            i++;
        }
        else{
            this->writeKeycode(HID_KEY_8, KEYBOARD_MODIFIER_RIGHTALT);  //if second square bracket not found, send single bracket
        }
        continue;
    }
    if(charToInterpret == ']'){                 //checks for ']'
        this->writeKeycode(HID_KEY_9, KEYBOARD_MODIFIER_RIGHTALT);
        continue;
    }
    if(charToInterpret == '^'){                 //checks for '^'
      writeKeycode(HID_KEY_GRAVE);     
      //cout<<"send funny to the power of symbol thingymabob"<<endl;
        continue;
    }
    if(charToInterpret == 92){
      this->backslash();
      continue;
    }
/////////////////////////////////////////////////////////////end////////////////////////////////////////////////////////////////////////
  }
  if(inBuffer){                       //runs, if last character war part of the printable characters from write()
      write(bufferString);
      bufferString.remove(0, (bufferString.length()));
      inBuffer = 0;
  }
}

void Keyboard::init(){          //sets up flash and runs initial read of file
  usb_hid.begin();
  while( !TinyUSBDevice.mounted() ){
    delay(100);
    Serial.print("Crashing");
  } 
  keymap_ptr = std::unique_ptr<Keymap>(new Keymap(filename, ammountLayers, ammountKeys));
  keymap_ptr->init();
  flash_setup();
  readFile();
}
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

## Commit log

2022-10-28 first release
    [Assem1.SLDASM, Body.SLDPRT, Body.STL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]
2022-12-10 Backup with Serial prints for debugging
2022-12-10 added Filereadin
    [Body no Display.STEP, Body no Display.STL, Body.STEP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]
2022-12-11 fixed some bugs and added comments
    [Keyboard.cpp, Macruwu_OS.ino, file_management.cpp]
2022-12-11 updated 3D moddels
    [Keyplate 14.0mm.STL, Keyplate 14.1mm.STL, Keyplate 14.2mm.STL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]
2022-12-12 fixed body to fit MX hotswap sockets
    [Body no Display.STEP, Body no Display.STL]
2023-01-06 updated 3D models
    [Body no Display.STEP, Body no Display.STL, Body.STEP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]
2023-01-11 minor cleanup
    [PCB_Macro Pad_2022-10-13.dxf, The Macruwu.kicad_pcb]
2023-02-06 started documentation in I2C
